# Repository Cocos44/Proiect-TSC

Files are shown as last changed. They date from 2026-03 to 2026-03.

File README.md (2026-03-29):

# Proiect InkTime - Smartwatch

Un smartwatch bazat pe microcontrollerul Nordic nRF52840 cu display e-Paper.

---

## Diagrama bloc

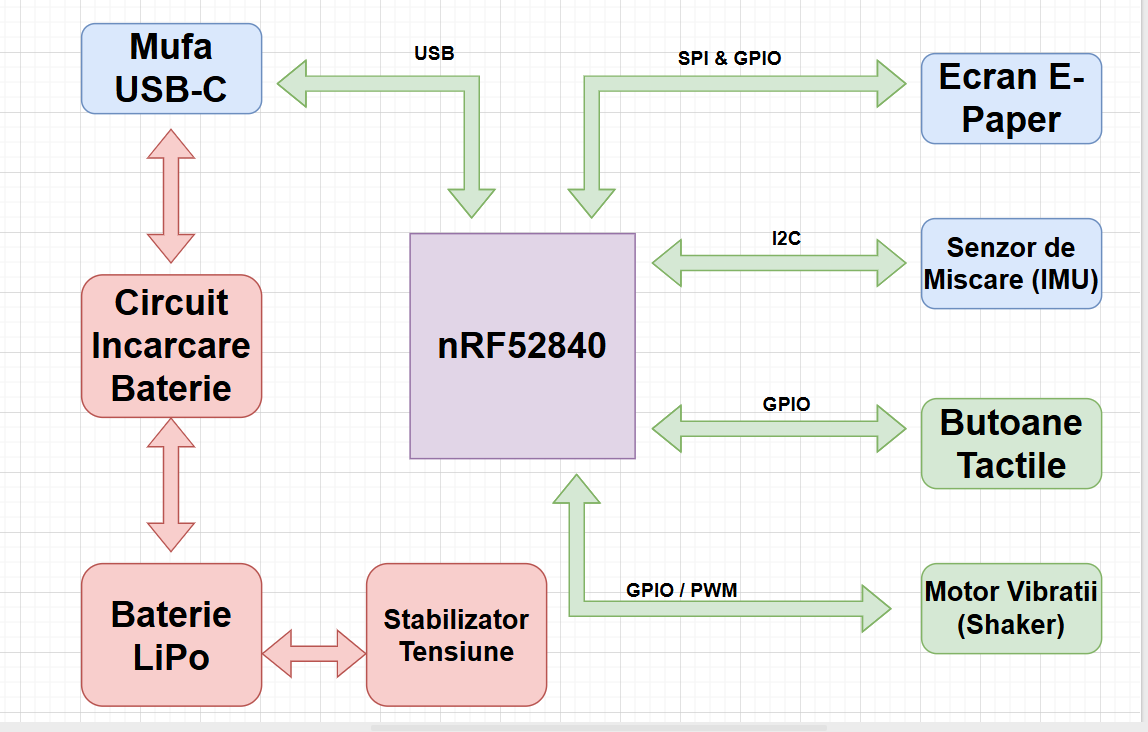
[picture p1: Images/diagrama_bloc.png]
Diagrama Bloc


---

## Bill of Materials

| Ref | Componenta | Valoare | JLC Parts | Datasheet |
|-----|---|---|---|---|
| U1 | nRF52840 | $5.14 | [JLC](https://jlcpcb.com/parts/componentSearch?searchTxt=nRF52840-QF) | [DS](https://jlcpcb.com/api/file/downloadByFileSystemAccessId/8589839228197629952) |
| SWD | TC2030-IDC | $100.26 | [JLC](https://jlcpcb.com/partdetail/MicrochipTech-TC2030_CLIP3PACK/C5444772) | [DS](https://www.lcsc.com/datasheet/lcsc_datasheet_2403201318_Microchip-Tech-TC2030-CLIP-3PACK_C5444772.pdf) |
| ANT1 | 2450AT18B100E | $1.03 | [JLC](https://jlcpcb.com/partdetail/JohansonDielectrics-2450AT18B100E/C2917717) | [DS](https://jlcpcb.com/api/file/downloadByFileSystemAccessId/8588940948130156544) |
| X1 | NX2016SA-32MHZ-EXS00A-CS11336 | $9.04 | [JLC](https://jlcpcb.com/partdetail/NDK-NX2016SA_32MHZ_EXS00ACS11336/C6134317) | [DS](https://jlcpcb.com/api/file/downloadByFileSystemAccessId/8603064888214908928) |
| L2 | RC0402JR-070RL | $0.01 | [JLC](https://jlcpcb.com/partdetail/YAGEO-RC0402JR070RL/C60485) | [DS](https://jlcpcb.com/api/file/downloadByFileSystemAccessId/8717146932348461056) |
| L3 | RC0402JR-070RL | $0.01 | [JLC](https://jlcpcb.com/partdetail/YAGEO-RC0402JR070RL/C60485) | [DS](https://jlcpcb.com/api/file/downloadByFileSystemAccessId/8717146932348461056) |
| X2 | FC-135_32.7680KA-A3 | $0.2677 | [JLC](https://jlcpcb.com/partdetail/SeikoEpson-FC_135_32_7680KAA3/C2650472) | [DS](https://jlcpcb.com/partdetail/SeikoEpson-FC_135_32_7680KAA3/C2650472) |
| IC3 | BMA423 | $11.30 | [JLC](https://jlcpcb.com/partdetail/BoschSensortec-BMA423/C189517) | [DS](https://jlcpcb.com/api/file/downloadByFileSystemAccessId/8588894317147017216) |
| IC9 | RT6160 | $0.56 | [JLC](https://jlcpcb.com/partdetail/RichtekTech-RT6160AWSC/C7065276) | [DS](https://jlcpcb.com/api/file/downloadByFileSystemAccessId/8600398231234883584) |
| L7 | MLP2016SR47MT0S1 | $0.10 | [JLC](https://jlcpcb.com/partdetail/TDK-MLP2016SR47MT0S1/C87545) | [DS](https://jlcpcb.com/api/file/downloadByFileSystemAccessId/8588933367512879104) |
| IC1 | BQ25180YBGR | $2.01 | [JLC](https://jlcpcb.com/partdetail/TexasInstruments-BQ25180YBGR/C3682423) | [DS](https://www.ti.com/cn/lit/gpn/bq25180) |
| L5 | 744043680 | $9.53 | [JLC](https://jlcpcb.com/partdetail/WurthElektronik-744043680/C2045671) | [DS](https://www.we-online.com/components/products/datasheet/744043680.pdf) |
| D2 | MBR0530 | $0.03 | [JLC](https://jlcpcb.com/partdetail/78464-MBR0530/C77336) | [DS](https://jlcpcb.com/api/file/downloadByFileSystemAccessId/8586175081181818880) |
| D4 | MBR0530 | $0.03 | [JLC](https://jlcpcb.com/partdetail/78464-MBR0530/C77336) | [DS](https://jlcpcb.com/api/file/downloadByFileSystemAccessId/8586175081181818880) |
| D5 | MBR0530 | $0.03 | [JLC](https://jlcpcb.com/partdetail/78464-MBR0530/C77336) | [DS](https://jlcpcb.com/api/file/downloadByFileSystemAccessId/8586175081181818880) |
| Q3 | SI1308EDL-T1-GE3 | $0.18 | [JLC](https://jlcpcb.com/partdetail/VishayIntertech-SI1308EDL_T1GE3/C469327) | [DS](https://jlcpcb.com/api/file/downloadByFileSystemAccessId/8588884784742846464) |
| Q1 | DMG2305UX-7 | $0.10 | [JLC](https://jlcpcb.com/partdetail/DiodesIncorporated-DMG2305UX7/C150470) | [DS](https://jlcpcb.com/api/file/downloadByFileSystemAccessId/8560079443617075200) |
| IC2 | DRV2605YZFR | $1.31 | [JLC](https://jlcpcb.com/partdetail/TexasInstruments-DRV2605YZFR/C81079) | [DS](https://www.ti.com/cn/lit/gpn/drv2605) |
| D3 | USBLC6-2SC6Y | $0.24 | [JLC](https://jlcpcb.com/partdetail/STMicroelectronics-USBLC62SC6Y/C2969755) | [DS](https://jlcpcb.com/api/file/downloadByFileSystemAccessId/8603165824304111616) |
| J4 | KH-TYPE-C-16P | $0.08 | [JLC](https://jlcpcb.com/partdetail/Shenzhen_KinghelmElec-KH_TYPE_C16P/C709357) | [DS](https://jlcpcb.com/api/file/downloadByFileSystemAccessId/8588905154556923904) |
| U3 | MAX17048G-T10 | $2.44 | [JLC](https://jlcpcb.com/partdetail/2777647-MAX17048GT10/C2682616) | [DS](https://jlcpcb.com/api/file/downloadByFileSystemAccessId/8588907428524003328) |
| J1 | 503480-2400 | $0.84 | [JLC](https://jlcpcb.com/partdetail/MOLEX-5034802400/C122434) | [DS](https://www.molex.com/content/dam/molex/molex-dot-com/products/automated/en-us/salesdrawingpdf/503/503480/5034802400_sd.pdf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) |

---

## Descriere Functionalitate Hardware

### Microcontroller - nRF52840
 Caracteristici principale:
- ARM Cortex-M4 la 64 MHz
- 1MB Flash, 256KB RAM
- Bluetooth 5.0 / BLE integrat
- Radio 2.4GHz cu suport pentru antena externa
- Interfete multiple: SPI, I2C, UART, GPIO
 
### Display E-Paper - Waveshare 1.54" V2
 
Display-ul comunica prin SPI pe 4 fire:
- Rezolutie: 200x200 pixeli
- Consum ultra-redus - retine imaginea fara alimentare
- Conectat la nRF52840 prin conectorul FPC 24 pini (503480-2400)
 
### IMU - BMA423
 
Accelerometrul BMA423 comunica prin I2C:
- Accelerometru pe 3 axe
- Numarare pasi, recunoastere activitate
 
### Incarcator Baterie - BQ25180
 
BQ25180 gestioneaza incarcarea bateriei prin I2C:
- Intrare: USB-C 5V
- Iesire: 3.7V LiPo
- Curent maxim de incarcare: 250mA
 
### Baterie - AKYGA LP502030
 
- Dimensiuni: 32.5mm x 21mm x 5.5mm
- Conectata direct la doua test pad-uri de pe placa
 
### Motor Vibratii - FIT0774
 
- Controlat prin GPIO via driver haptic DRV2605
- Diametru: 10mm, Inaltime: 2.7mm
- Tensiune de operare: 1.5-4.2V
 
### Conector Debug - TC2030-IDC
 
- Conector Tag-Connect 10 pini
- Folosit pentru programare si debugging SWD
- Semnale: SWDIO, SWDCLK, GND, VCC, RESET
 
---
 
## Pinii nRF52840
 
| Pin nRF52840 | Semnal | Componenta | Interfata |
|---|---|---|---|
| P0.00/XL1 | XL1 | Crystal X2 (32.768kHz) | XTAL |
| P0.01/XL2 | XL2 | Crystal X2 (32.768kHz) | XTAL |
| P0.05/AIN3 | EPD_CS | E-Paper (J1 FPC) | SPI CS |
| P0.06 | SDA | BMA423, BQ25180, MAX17048, DRV2605 | I2C SDA |
| P0.07 | SCL | BMA423, BQ25180, MAX17048, DRV2605 | I2C SCL |
| P0.08 | IMU_INT1 | BMA423 | GPIO Input |
| P1.08 | IMU_INT2 | BMA423 | GPIO Input |
| P0.11 | PMIC_INT | BQ25180 | GPIO Input |
| P0.12 | HAPTIC_EN | DRV2605 | GPIO |
| VBUS | VBUS | USB-C (J4) | Power |
| D- | D- | USB-C (J4) / USBLC6 | USB |
| D+ | D+ | USB-C (J4) / USBLC6 | USB |
| P0.13 | SW_UP | Buton Up | GPIO Input |
| P0.14 | SW_ENT | Buton Enter | GPIO Input |
| P0.15 | EPD_DC | E-Paper (J1 FPC) | SPI DC |
| P0.16 | EPD_RST | E-Paper (J1 FPC) | GPIO |
| P0.17 | EPD_BUSY | E-Paper (J1 FPC) | GPIO Input |
| P0.18/RESET | RESET | TC2030-IDC | SWD/GPIO |
| SWDCLK | SWDCLK | TC2030-IDC | SWD |
| SWDIO | SWDIO | TC2030-IDC | SWD |
| P1.02 | SW_DN | Buton Down | GPIO Input |
| P0.10/NFC2 | ALERT | MAX17048 | GPIO Input |
| ANT | RF | Antena 2450AT18B100E | RF |
| P0.02/AIN0 | SCK | E-Paper (J1 FPC) | SPI SCK |
| P0.03/AIN1 | MOSI | E-Paper (J1 FPC) | SPI MOSI |
 
---

## Jurnal de Design si Pasi de Implementare (Design Log)

### Pasi realizare PCB
* Plasarea componentelor majore: Am inceput prin a pozitiona componentele mari si cele cu constrangeri mecanice stricte (mufa USB, butoanele laterale, conectorul de display si microcontrollerul). Imediat dupa plasarea componentelor principale, am legat componentele mici (condensatoare, rezistente, etc.). In final, am pus Polygon Pour pe toate planurile infara de cel de POWER.

* Dupa plasarea componentelor in PCB, am inceput rutarea mai intai cu traseele de putere, urmand dupa cu restul.

* Rutarea (Top/Bottom): Traseele au fost rutate evitand unghiurile drepte. Liniile de alimentare au fost dimensionate cu latimea de 0.3mm (variind sub zonele dense BGA/QFN), iar cele de date la 0.15mm. Zona de sub antena radio a fost curatata complet de cupru si semnale.

### Erori DRC acceptate
* Copper Clearance: In zona pad-urilor BGA ale nRF52840, distanta minima dintre pad-uri este impusa de producator si nu poate fi modificata. Erorile sunt inevitabile si acceptate de JLCPCB.

* Overlap: Aceste erori apar din cauza tehnicii Via-in-Pad. Via-urile plasate direct in pad-urile componentei se suprapun geometric cu traseele adiacente.

* Drill Size: Via-urile folosite pentru Via-in-Pad au diametrul mai mic decat minimul din regulile DRC standard, ales intentionat pentru a incapea in pad-urile mici ale nRF52840.

* Board Outline Clearance. Erori de la mufa USB-C.
---

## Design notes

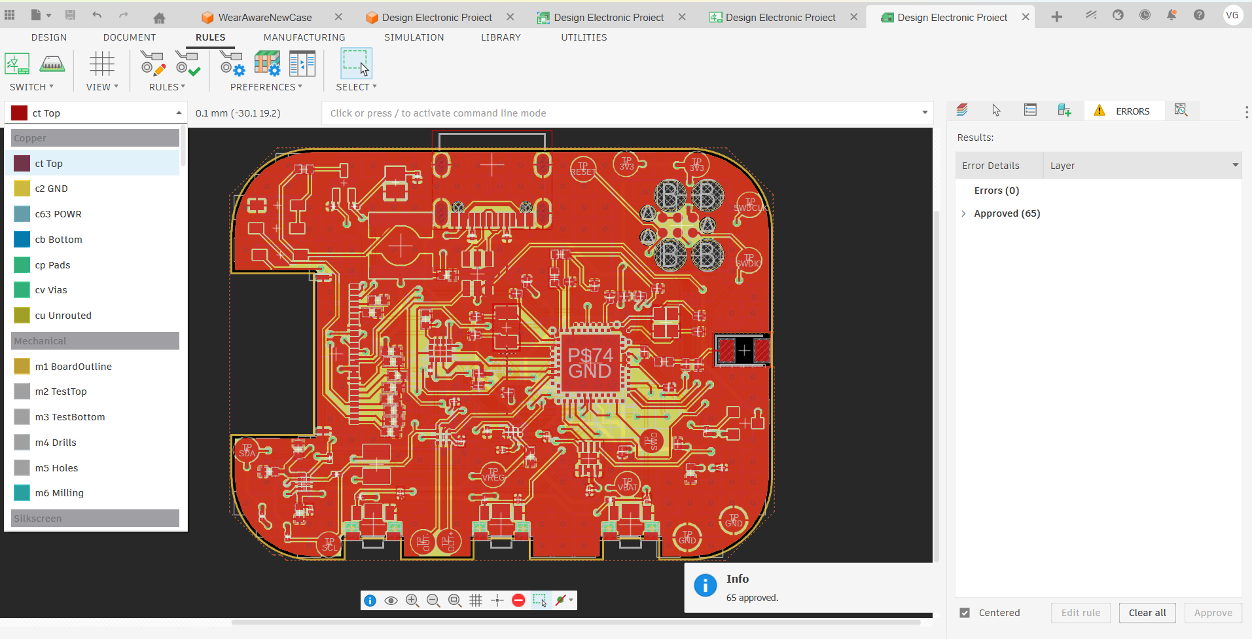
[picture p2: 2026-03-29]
Images/pcb_plus_rulare_drc.png

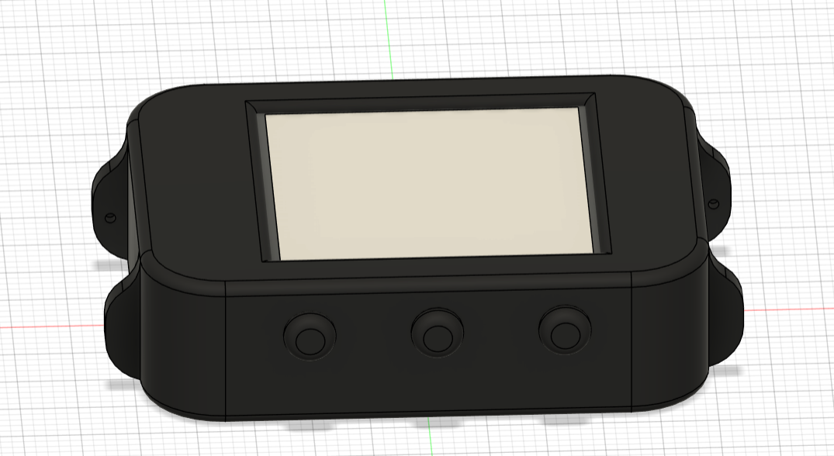
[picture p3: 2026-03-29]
Images/ceas_forma_finala.png

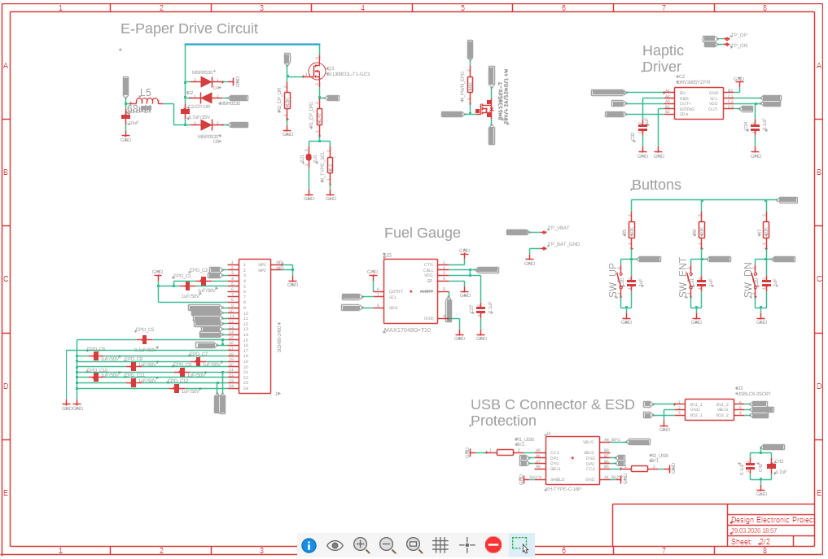
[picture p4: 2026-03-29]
Images/schema_electrica_fisa_2.png

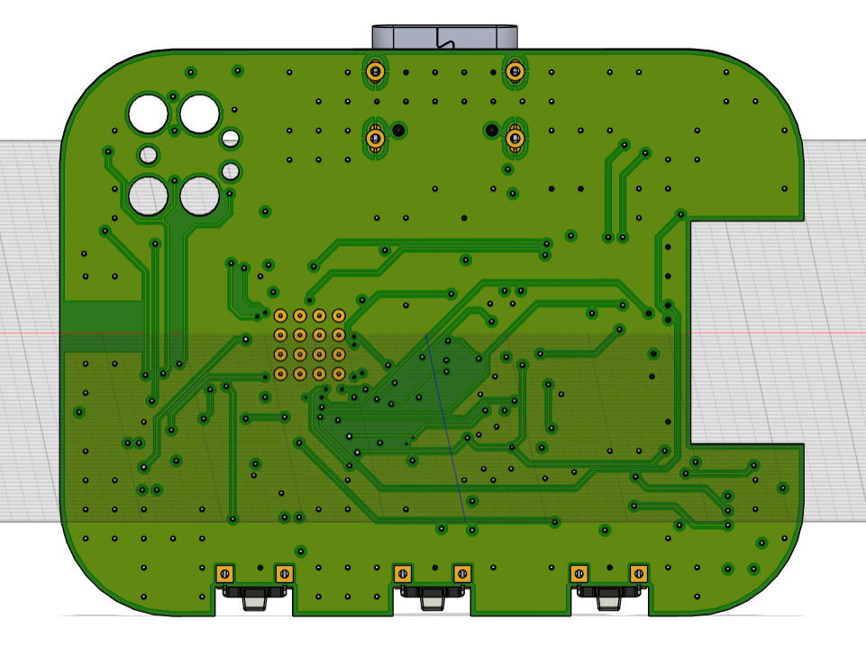
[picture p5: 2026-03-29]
Images/pcb-3D_spate.png

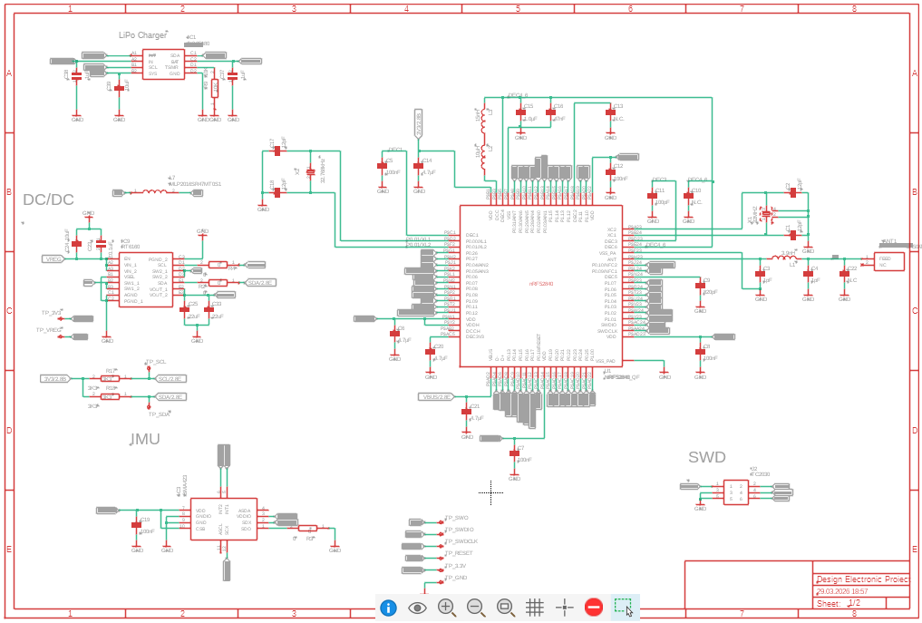
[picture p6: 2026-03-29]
Images/schema_electrica_fisa_1.png

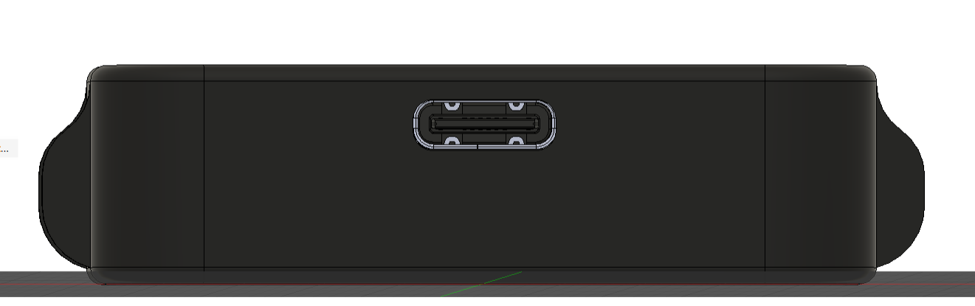
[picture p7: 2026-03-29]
Images/ceas_mufa_usb_plasare_corecta.png

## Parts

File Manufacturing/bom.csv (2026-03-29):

Qty | Value | Device | Package | Parts | Description | 2450AT18B100E | ARROW_PART_NUMBER | ARROW_PRICE-STOCK | AVAILABILITY | BQ25180 | BQ25180YBGR | CHECK_PRICES | COPYRIGHT | DESCRIPTION | DIGI-KEY_PART_NUMBER_1 | DIGI-KEY_PART_NUMBER_2 | DIGI-KEY_PART_NUMBER_3 | HEIGHT | JLCPCB | MANUFACTURER_NAME | MANUFACTURER_PART_NUMBER | MF | MFR_NAME | MOUSER_PART_NUMBER | MOUSER_PRICE-STOCK | MP | NRF52840_QF | PACKAGE | POPULARITY | PRICE | PROD_ID | PURCHASE-URL | R1 | SHOW_VALUE | SNAPEDA_LINK | TP_SIGNAL_NAME | VALUE
1 | nRF52840 | NORDIC_NRF_4_NRF52840_QF | NORDIC_NRF_4_AQFN50P700X700X85_HS-74N | U1 | nRF52840
3 | 0 | CPF0201D7K68C1_CPF0201D7K68C1 | CPF0201D7K68C1_0201 | R2, R3, R4 | 7.68k 0201 Thin Film Surface Mount Fixed Resistor +/-0.5% 0.031W CPF0201D7K68C1 |  |  |  |  |  |  |  |  |  |  |  |  |  |  |  |  |  |  |  |  |  |  |  |  |  |  |  | 0
4 | 0.1uF | GRM011R60J152KE01L_2_GRM011R60J152KE01L | GRM011R60J152KE01L_2_CAPC0201X13N | C23, C27, C34, C42 | Check availability |  |  |  | In Stock |  |  | https://www.snapeda.com/parts/GRM011R60J152KE01L/Murata/view-part/?ref=eda |  | SMD Capacitor X5R(EIA) with Capacitance: 1500pF Tol. 10%. Rated Voltage: 6.3Vdc |  |  |  |  |  |  |  | Murata |  |  |  | GRM011R60J152KE01L |  | 0201 Murata |  | None |  |  |  |  | https://www.snapeda.com/parts/GRM011R60J152KE01L/Murata/view-part/?ref=snap
1 | 0.1uF/50V | NORDIC_NRF_3_CAPACITOR_0402_L | NORDIC_NRF_3_RESC0402_L | EPD_C5 | Generic chip capacitor
1 | 0.47 | CPF0201D7K68C1_CPF0201D7K68C1 | CPF0201D7K68C1_0201 | R1_EP_DR1 | 7.68k 0201 Thin Film Surface Mount Fixed Resistor +/-0.5% 0.031W CPF0201D7K68C1
1 | 1.0µF | NORDIC_NRF_3_CAPACITOR_0201_L | NORDIC_NRF_3_RESC0201_L | C15 | Generic chip capacitor
4 | 100nF | NORDIC_NRF_3_CAPACITOR_0201_L | NORDIC_NRF_3_RESC0201_L | C5, C7, C8, C12 | Generic chip capacitor
1 | 100nF | NORDIC_NRF_3_CAPACITOR_0402_L | NORDIC_NRF_3_RESC0402_L | C19 | Generic chip capacitor
1 | 100pF | NORDIC_NRF_3_CAPACITOR_0201_L | NORDIC_NRF_3_RESC0201_L | C11 | Generic chip capacitor
5 | 10K | CPF0201D7K68C1_CPF0201D7K68C1 | CPF0201D7K68C1_0201 | R2_EP_DR, R5, R7, R8, R_PWR_EPD | 7.68k 0201 Thin Film Surface Mount Fixed Resistor +/-0.5% 0.031W CPF0201D7K68C1
1 | 10K | CPF0201D7K68C1_CPF0201D7K68C1 | CPF0201D7K68C1_0201 | R9 | 7.68k 0201 Thin Film Surface Mount Fixed Resistor +/-0.5% 0.031W CPF0201D7K68C1 |  |  |  |  |  |  |  |  |  |  |  |  |  |  |  |  |  |  |  |  |  |  |  |  |  |  |  | 10K
3 | 10uF | NORDIC_NRF_3_CAPACITOR_0402_L | NORDIC_NRF_3_RESC0402_L | C1-EP-DR, C24, C39 | Generic chip capacitor
1 | 10µH | NORDIC_NRF_2_INDUCTOR_0402_L | NORDIC_NRF_2_RESC0402_L | L2 | Generic chip inductor
4 | 12pF | NORDIC_NRF_3_CAPACITOR_0201_L | NORDIC_NRF_3_RESC0201_L | C1, C2, C17, C18 | Generic chip capacitor
1 | 15nH | NORDIC_NRF_2_INDUCTOR_0402_L | NORDIC_NRF_2_RESC0402_L | L3 | Generic chip inductor
2 | 1pF | NORDIC_NRF_3_CAPACITOR_0201_L | NORDIC_NRF_3_RESC0201_L | C3, C4 | Generic chip capacitor
6 | 1uF | GRM011R60J152KE01L_2_GRM011R60J152KE01L | GRM011R60J152KE01L_2_CAPC0201X13N | C29, C30, C31, C32, C37, C38 | Check availability |  |  |  | In Stock |  |  | https://www.snapeda.com/parts/GRM011R60J152KE01L/Murata/view-part/?ref=eda |  | SMD Capacitor X5R(EIA) with Capacitance: 1500pF Tol. 10%. Rated Voltage: 6.3Vdc |  |  |  |  |  |  |  | Murata |  |  |  | GRM011R60J152KE01L |  | 0201 Murata |  | None |  |  |  |  | https://www.snapeda.com/parts/GRM011R60J152KE01L/Murata/view-part/?ref=snap
9 | 1uF/50V | NORDIC_NRF_3_CAPACITOR_0402_L | NORDIC_NRF_3_RESC0402_L | EPD_C1, EPD_C2, EPD_C6, EPD_C7, EPD_C8, EPD_C9, EPD_C10, EPD_C11, EPD_C12 | Generic chip capacitor
1 | 2.2 | CPF0201D7K68C1_CPF0201D7K68C1 | CPF0201D7K68C1_0201 | R_TYPE_SEL | 7.68k 0201 Thin Film Surface Mount Fixed Resistor +/-0.5% 0.031W CPF0201D7K68C1
3 | 2025-10-22_07-23-44_LIBRARY_EVP-AKE31ASW_EVP-AKE31A_PAN | 2025-10-22_07-23-44_LIBRARY_EVP-AKE31ASW_EVP-AKE31A_PAN | 2025-10-22_07-23-44_LIBRARY_SW_EVP-AKE31A_PAN | SW_DN, SW_ENT, SW_UP |  |  |  |  |  |  |  |  | Copyright (C) 2025 Ultra Librarian. All rights reserved. |  | P123437TR-ND | P123437CT-ND | P123437DKR-ND |  |  | Panasonic | EVP-AKE31A
1 | 20V/4.2A/52m?/1.4W | ESP32_C6_LIBRARY_4_ESP32_WROVER_SPARKFUN-DISCRETESEMI_MOSFET_PCH-DMG2305UX-7 | ESP32_C6_LIBRARY_4_ESP32_C6_LIBRARY_4_ESP32_C6_LIBRARY_4_ESP32_C6_LIBRARY_4_ESP32_WROVER_SPARKFUN-DISCRETESEMI_SOT23-3 | DMG2305UX-7 | P-channel MOSFETs |  |  |  |  |  |  |  |  |  |  |  |  |  |  |  |  |  |  |  |  |  |  |  |  |  | TRAN-14388 |  |  |  |  |  | 20V/4.2A/52m?/1.4W
2 | 22uF | NORDIC_NRF_3_CAPACITOR_0402_L | NORDIC_NRF_3_RESC0402_L | C25, C33 | Generic chip capacitor
1 | 2450AT18B100E_2450AT18B100E | 2450AT18B100E_2450AT18B100E | 2450AT18B100E_ANTC3216X140N | ANT1 | Antennas 2.45GHz ANTENNA |  | 2450AT18B100E | https://www.arrow.com/en/products/2450at18b100e/johanson-dielectrics?utm_currency=USD&region=nac |  |  |  |  |  | Antennas 2.45GHz ANTENNA |  |  |  | 1.4mm |  | JOHANSON TECHNOLOGY | 2450AT18B100E |  |  | 609-2450AT18B100E | https://www.mouser.co.uk/ProductDetail/Johanson-Technology/2450AT18B100E?qs=yCnrNFeXz%252Bh5MFsFIXGZGA%3D%3D
1 | 3.9nH | NORDIC_NRF_2_INDUCTOR_0402_L | NORDIC_NRF_2_RESC0402_L | L1 | Generic chip inductor
1 | 32.768kHz | NORDIC_NRF_1_XTAL_32KHZ | NORDIC_NRF_1_XTAL_3215_N | X2
1 | 32MHZ | NORDIC_NRF_XTAL_32MHZ | NORDIC_NRF_BT-XTAL_2016_N | X1
2 | 3K3 | CPF0201D7K68C1_CPF0201D7K68C1 | CPF0201D7K68C1_0201 | R17, R18 | 7.68k 0201 Thin Film Surface Mount Fixed Resistor +/-0.5% 0.031W CPF0201D7K68C1 |  |  |  |  |  |  |  |  |  |  |  |  |  |  |  |  |  |  |  |  |  |  |  |  |  |  |  | 3K3
1 | 4.7uF | NORDIC_NRF_3_CAPACITOR_0402_L | NORDIC_NRF_3_RESC0402_L | C43 | Generic chip capacitor
1 | 4.7uF/25V | NORDIC_NRF_3_CAPACITOR_0402_L | NORDIC_NRF_3_RESC0402_L | C2-EP-DR | Generic chip capacitor
4 | 4.7µF | NORDIC_NRF_3_CAPACITOR_0201_L | NORDIC_NRF_3_RESC0201_L | C6, C14, C20, C21 | Generic chip capacitor
1 | 47nF | NORDIC_NRF_3_CAPACITOR_0201_L | NORDIC_NRF_3_RESC0201_L | C16 | Generic chip capacitor
1 | 503480-2400 | 503480-2400_503480-2400 | 503480-2400_5034802400 | J1 | FFC & FPC Connectors 0.5mm FPC RA SMT Dual Contact 24Ckt |  |  |  |  |  |  |  |  | FFC & FPC Connectors 0.5mm FPC RA SMT Dual Contact 24Ckt |  |  |  | 1.87mm |  | Molex | 503480-2400 |  |  | 538-503480-2400 | https://www.mouser.co.uk/ProductDetail/Molex/503480-2400?qs=OAhjpuo3Vu7efIoxFh9AOw%3D%3D
2 | 5K1 | CPF0201D7K68C1_CPF0201D7K68C1 | CPF0201D7K68C1_0201 | R1_USB, R2_USB | 7.68k 0201 Thin Film Surface Mount Fixed Resistor +/-0.5% 0.031W CPF0201D7K68C1
1 | 68uH | ESP32_C6_LIBRARY_2_744043680IND_4828-WE-TPC_WRE | ESP32_C6_LIBRARY_2_IND_4828-WE-TPC_WRE | L5 |  |  |  |  |  |  |  |  | Copyright (C) 2024 Ultra Librarian. All rights reserved. |  |  |  |  |  |  |  | 744043680 |  | Wurth Electronics |  |  |  |  |  |  |  |  |  |  | 68uH
1 | 820pF | NORDIC_NRF_3_CAPACITOR_0201_L | NORDIC_NRF_3_RESC0201_L | C9 | Generic chip capacitor
1 | BMA423 | BMA423_BMA423 | BMA423_BMA423 | IC3 | Accelerometers Triaxial low-g 12bit Acceleration Sensor |  | BMA423 | https://www.arrow.com/en/products/bma423/bosch |  |  |  |  |  | Accelerometers Triaxial low-g 12bit Acceleration Sensor |  |  |  | 1mm |  | BOSCH | BMA423 |  |  | 262-BMA423 | https://www.mouser.co.uk/ProductDetail/Bosch-Sensortec/BMA423?qs=HXFqYaX1Q2xC%252BSgeGoX3mg%3D%3D
1 | BQ25180 | BQ25180YBGR_BQ25180YBGR | BQ25180YBGR_BGA8C40P2X4_100X155X50 | IC1 | Charger IC Lithium Ion/Polymer, Lithium Iron Phosphate 8-DSBGA (1.6x1.1) |  | BQ25180YBGR | https://www.arrow.com/en/products/bq25180ybgr/texas-instruments?utm_currency=USD&region=nac |  |  |  |  |  | Charger IC Lithium Ion/Polymer | Lithium Iron Phosphate 8-DSBGA (1.6x1.1) |  |  |  | 0.5mm |  | Texas Instruments | BQ25180YBGR |  |  | 595-BQ25180YBGR | https://www.mouser.co.uk/ProductDetail/Texas-Instruments/BQ25180YBGR?qs=doiCPypUmgEWjAK%252BJAX6Tw%3D%3D
1 | DRV2605YZFR | DRV2605YZFR_DRV2605YZFR | DRV2605YZFR_BGA9C50P3X3_144X144X62 | IC2 | Haptic Driver for ERM/LRA with Built-In Library and Smart Loop Architecture |  | DRV2605YZFR | https://www.arrow.com/en/products/drv2605yzfr/texas-instruments?region=nac |  |  |  |  |  | Haptic Driver for ERM/LRA with Built-In Library and Smart Loop Architecture |  |  |  | 0.625mm |  | Texas Instruments | DRV2605YZFR
14 | HECTOR_WATCH_1_TPTP20R | HECTOR_WATCH_1_TPTP20R | HECTOR_WATCH_1_TP20R | TP_3.3V, TP_3V3, TP_BAT_GND, TP_GND, TP_ON, TP_OP, TP_RESET, TP_SCL, TP_SDA, TP_SWDCLK, TP_SWDIO, TP_SWO, TP_VBAT, TP_VREG | Test pad |  |  |  |  |  |  |  |  |  |  |  |  |  |  |  |  |  |  |  |  |  |  |  | 2
1 | KH-TYPE-C-16P | KH-TYPE-C-16P_KH-TYPE-C-16P | KH-TYPE-C-16P_KINGHELM_KH-TYPE-C-16P | J4 | Check availability |  |  |  | Not in stock |  |  | https://www.snapeda.com/parts/KH-TYPE-C-16P/Kinghelm/view-part/?ref=eda |  |  |  |  |  |  |  |  |  | kinghelm |  |  |  | KH-TYPE-C-16P |  | None |  | None |  |  |  |  | https://www.snapeda.com/parts/KH-TYPE-C-16P/Kinghelm/view-part/?ref=snap
1 | MAX17048G+T10 | ESP32_C6_LIBRARY_MAX17048G+T10 | ESP32_C6_LIBRARY_SON50P200X200X80-9N | U3 | Check availability |  |  |  | In Stock |  |  | https://www.snapeda.com/parts/MAX17048G+T10/Analog+Devices/view-part/?ref=eda |  | 3µA 1-Cell/2-Cell Fuel Gauge with ModelGauge |  |  |  |  |  |  |  | Analog Devices |  |  |  | MAX17048G+T10 |  | TDFN-8 Maxim |  | None |  | https://www.snapeda.com/api/url_track_click_mouser/?unipart_id=329239&manufacturer=Analog Devices&part_name=MAX17048G+T10&search_term=None |  |  | https://www.snapeda.com/parts/MAX17048G+T10/Analog+Devices/view-part/?ref=snap
3 | MBR0530 | ESP32_C6_LIBRARY_5_MBR0530 | ESP32_C6_LIBRARY_5_SOD3716X135N | D2, D4, D5 | ON SEMICONDUCTOR - MBR0530 - DIODE, SCHOTTKY, 0.5A, 30V, SOD-123 |  |  |  | In Stock |  |  | https://www.snapeda.com/parts/MBR0530/Onsemi/view-part/?ref=eda |  | Diode Schottky 30 V 500mA Surface Mount SOD-123 |  |  |  |  |  |  |  | ON Semiconductor |  |  |  | MBR0530 |  | SOD-123-2 ON Semiconductor |  | None |  | https://www.snapeda.com/api/url_track_click_mouser/?unipart_id=179458&manufacturer=ON Semiconductor&part_name=MBR0530&search_term=None |  |  | https://www.snapeda.com/parts/MBR0530/Onsemi/view-part/?ref=snap
1 | MLP2016SR47MT0S1 | MLP2016SR47MT0S1_FTC252012SR47MBCA | MLP2016SR47MT0S1_INDC2016X100N | L7 | SMD / SMT Inductors (Coils), L=0.47?H, L x W x T : |  |  |  |  |  |  |  |  | SMD / SMT Inductors (Coils) | L=0.47?H | L x W x T : |  |  |  | 1mm | https://jlcpcb.com/partdetail/6763488-FTC252012SR47MBCA/C5832368 | TDK | FTC252012SR47MBCA
1 | N.C | NORDIC_NRF_3_CAPACITOR_0201_L | NORDIC_NRF_3_RESC0201_L | C22 | Generic chip capacitor
2 | N.C. | NORDIC_NRF_3_CAPACITOR_0201_L | NORDIC_NRF_3_RESC0201_L | C10, C13 | Generic chip capacitor
1 | RT6160 | RT6160AWSC_RT6160AWSC | RT6160AWSC_BGA15C40P3X5_140X230X60 | IC9 | Buck-Boost Regulator Positive Output Step-Up/Step-Down I2C DC-DC Controller IC 15-WL-CSP (BSC) (1.4x2.3) |  |  |  |  |  |  |  |  | Buck-Boost Regulator Positive Output Step-Up/Step-Down I2C DC-DC Controller IC 15-WL-CSP (BSC) (1.4x2.3) |  |  |  | 0.6mm |  | RICHTEK | RT6160AWSC |  |  | 835-RT6160AWSC | https://www.mouser.co.uk/ProductDetail/Richtek/RT6160AWSC?qs=amGC7iS6iy%2FLd9PSoixZXQ%3D%3D
1 | SI1308EDL-T1-GE3 | ESP32_C6_LIBRARY_6_SI1308EDL-T1-GE3 | ESP32_C6_LIBRARY_6_SOT65P210X110-3N | Q3 | MOSFET N-Ch 30V 1.5A TrenchFET SC70 Vishay Si1308EDL-T1-GE3 N-channel MOSFET Transistor, 1.5 A, 30 V, 3-Pin SC-70 |  |  |  | In Stock |  |  | https://www.snapeda.com/parts/SI1308EDL-T1-GE3/Vishay+Siliconix/view-part/?ref=eda |  | Si1308EDL-T1-GE3 N-channel MOSFET Transistor | 1.5 A | 30 V | 3-Pin SC-70 | Siliconix / Vishay SI1308EDL-T1-GE3 |  |  |  |  |  |  |  | Vishay Siliconix |  |  |  | SI1308EDL-T1-GE3 |  | SOT-323 Vishay Semiconductor |  | None |  | https://www.snapeda.com/api/url_track_click_mouser/?unipart_id=274603&manufacturer=Vishay Siliconix&part_name=SI1308EDL-T1-GE3&search_term=None
1 | SJ1 | ESP32_C6_LIBRARY_7_JUMPER_SJ | ESP32_C6_LIBRARY_7_JUMPER_SJ | SJ1 | SMD solder JUMPER |  |  |  |  |  |  |  |  |  |  |  |  |  |  |  |  |  |  |  |  |  |  |  | 3
1 | TC2030 | TC2030-IDC_TC2030-IDC | TC2030-IDC_TC2030IDC | J2 | CABLE ADAPTER 6 POS |  |  |  |  |  |  |  |  | CABLE ADAPTER 6 POS |  |  |  | 19mm |  | Tag Connect | TC2030-IDC
1 | USBLC6-2SC6Y | ESP32_C6_LIBRARY_3_USBLC6-2SC6Y | ESP32_C6_LIBRARY_3_SOT95P280X145-6N | D3 | Low Cap. ESD Protection Auto SOT-23-6 STMicroelectronics USBLC6-2SC6Y, Dual Uni-Directional TVS Diode Array, 6-Pin SOT-23 |  |  |  | In Stock |  |  | https://www.snapeda.com/parts/USBLC6-2SC6Y/STMicroelectronics/view-part/?ref=eda |  | 17V Clamp 5A (8/20µs) Ipp Tvs Diode Surface Mount SOT-23-6 |  |  |  |  |  |  |  | STMicroelectronics |  |  |  | USBLC6-2SC6Y |  | SOT-23-6 STMicroelectronics |  | None |  |  |  |  | https://www.snapeda.com/parts/USBLC6-2SC6Y/STMicroelectronics/view-part/?ref=snap

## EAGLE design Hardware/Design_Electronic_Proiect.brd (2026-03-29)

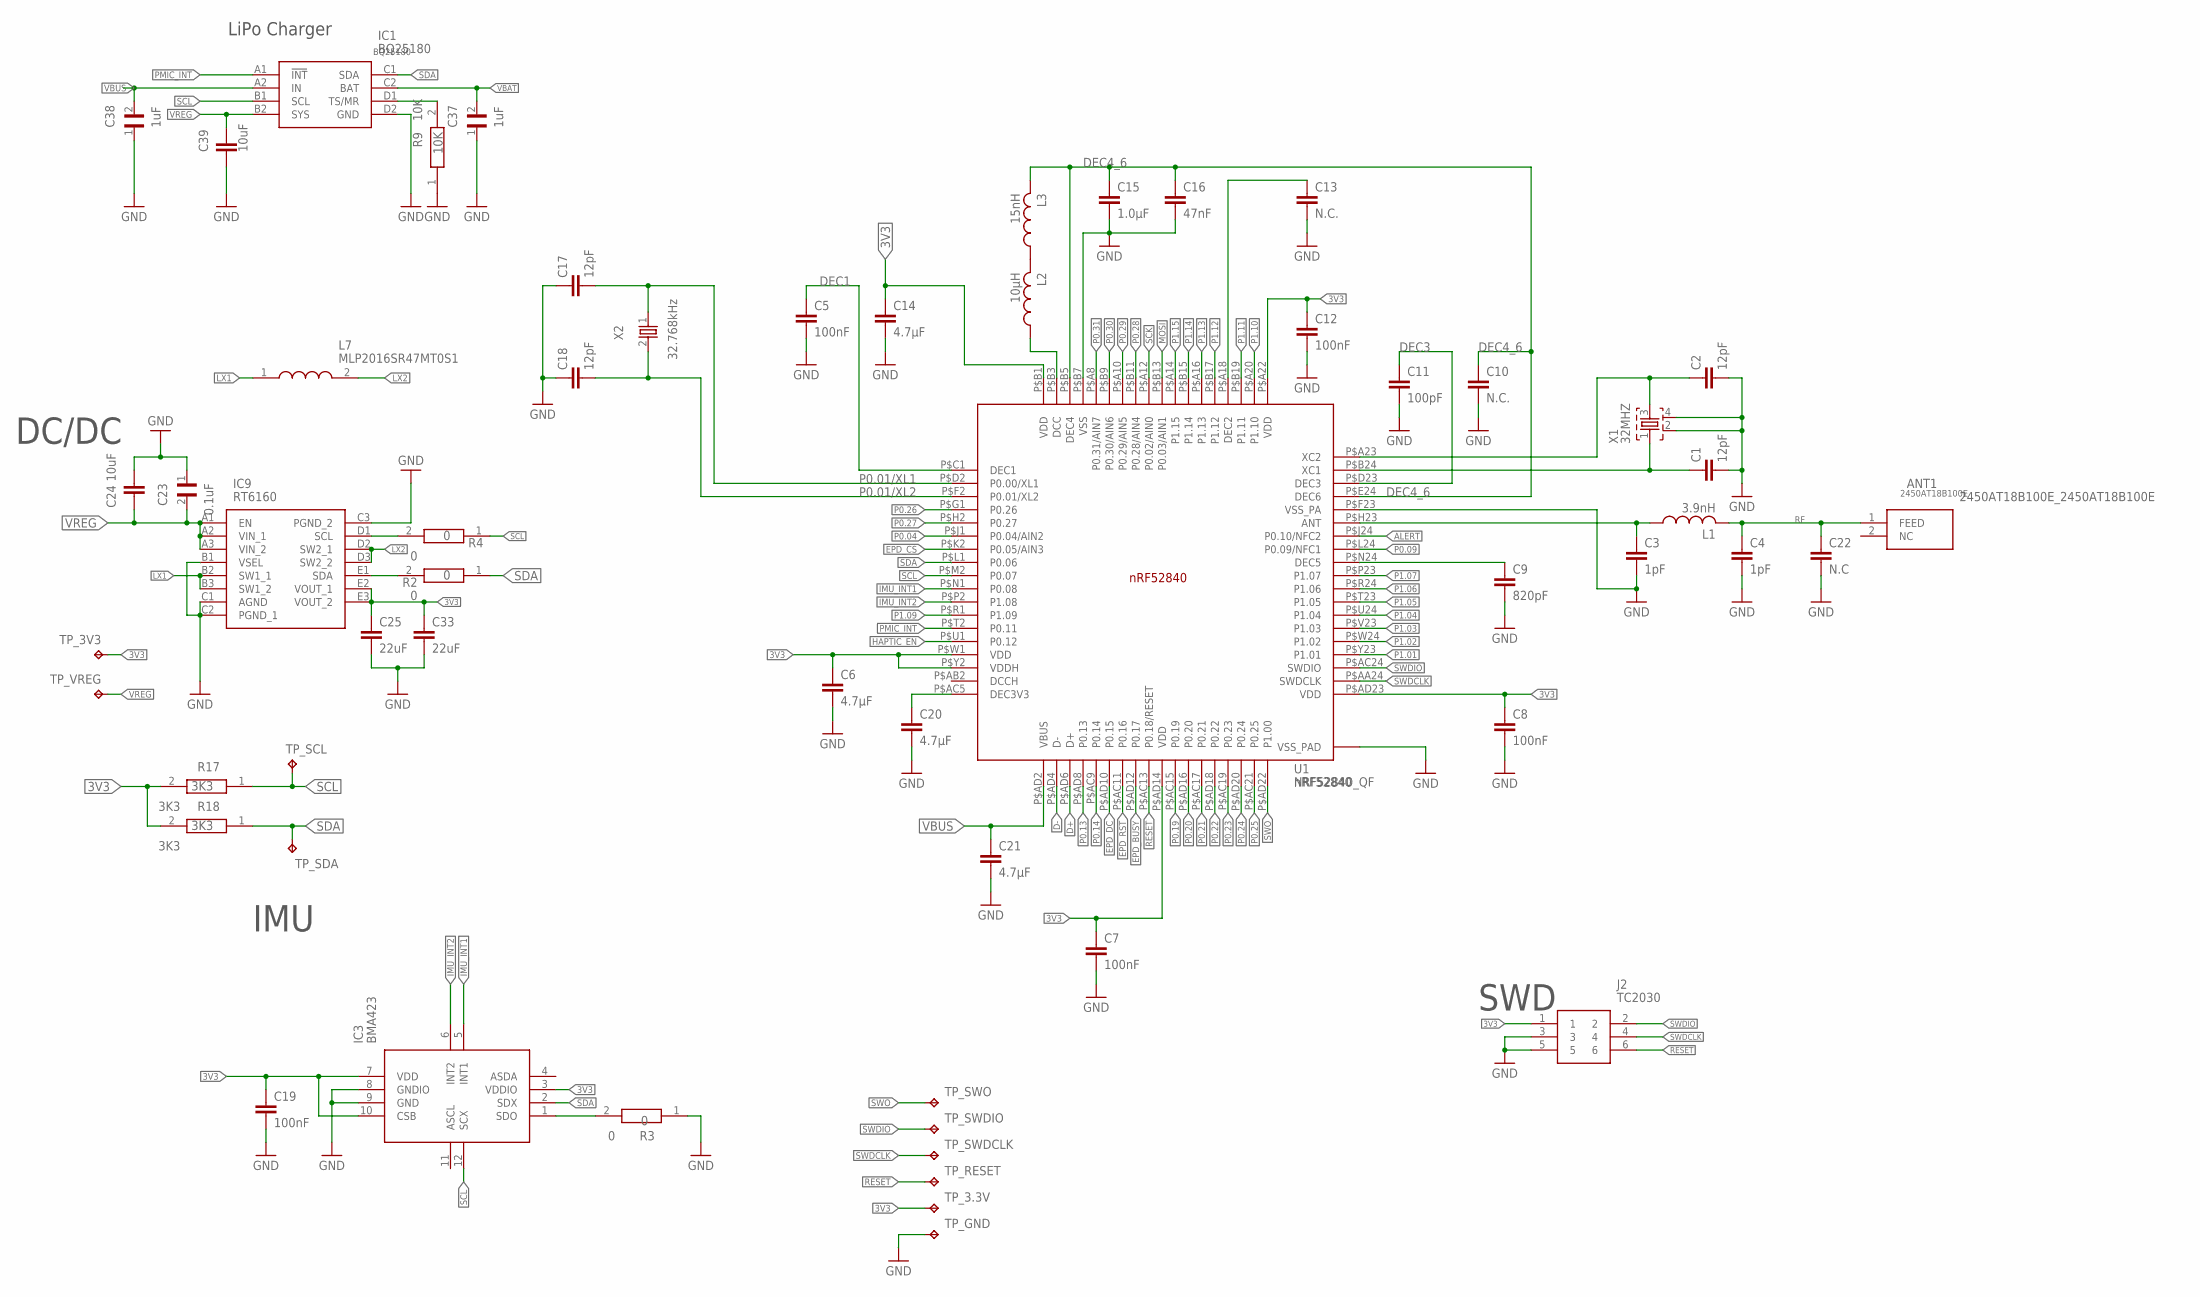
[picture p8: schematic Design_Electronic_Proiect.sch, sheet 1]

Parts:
ANT1: 2450AT18B100E_2450AT18B100E; 2450AT18B100E_ANTC3216X140N
C1, C2, C17, C18: 12pF; NORDIC_NRF_3_RESC0201_L
C3, C4: 1pF; NORDIC_NRF_3_RESC0201_L
C5, C7, C8, C12: 100nF; NORDIC_NRF_3_RESC0201_L
C6, C14, C20, C21: 4.7µF; NORDIC_NRF_3_RESC0201_L
C9: 820pF; NORDIC_NRF_3_RESC0201_L
C10, C13: N.C.; NORDIC_NRF_3_RESC0201_L
C11: 100pF; NORDIC_NRF_3_RESC0201_L
C15: 1.0µF; NORDIC_NRF_3_RESC0201_L
C16: 47nF; NORDIC_NRF_3_RESC0201_L
C19: 100nF; NORDIC_NRF_3_RESC0402_L
C22: N.C; NORDIC_NRF_3_RESC0201_L
C23: 0.1uF; GRM011R60J152KE01L_2_CAPC0201X13N
C24, C39: 10uF; NORDIC_NRF_3_RESC0402_L
C25, C33: 22uF; NORDIC_NRF_3_RESC0402_L
C37, C38: 1uF; GRM011R60J152KE01L_2_CAPC0201X13N
IC1: BQ25180; BQ25180YBGR_BGA8C40P2X4_100X155X50
IC3: BMA423; BMA423_BMA423
IC9: RT6160; RT6160AWSC_BGA15C40P3X5_140X230X60
J2: TC2030; TC2030-IDC_TC2030IDC
L1: 3.9nH; NORDIC_NRF_2_RESC0402_L
L2: 10µH; NORDIC_NRF_2_RESC0402_L
L3: 15nH; NORDIC_NRF_2_RESC0402_L
L7: MLP2016SR47MT0S1; MLP2016SR47MT0S1_INDC2016X100N
R2, R3, R4: 0; CPF0201D7K68C1_0201
R9: 10K; CPF0201D7K68C1_0201
R17, R18: 3K3; CPF0201D7K68C1_0201
TP_3.3V, TP_3V3: HECTOR_WATCH_1_TPTP20R; HECTOR_WATCH_1_TP20R
TP_GND: HECTOR_WATCH_1_TPTP20R; HECTOR_WATCH_1_TP20R
TP_RESET: HECTOR_WATCH_1_TPTP20R; HECTOR_WATCH_1_TP20R
TP_SCL: HECTOR_WATCH_1_TPTP20R; HECTOR_WATCH_1_TP20R
TP_SDA: HECTOR_WATCH_1_TPTP20R; HECTOR_WATCH_1_TP20R
TP_SWDCLK: HECTOR_WATCH_1_TPTP20R; HECTOR_WATCH_1_TP20R
TP_SWDIO: HECTOR_WATCH_1_TPTP20R; HECTOR_WATCH_1_TP20R
TP_SWO: HECTOR_WATCH_1_TPTP20R; HECTOR_WATCH_1_TP20R
TP_VREG: HECTOR_WATCH_1_TPTP20R; HECTOR_WATCH_1_TP20R
U1: nRF52840; NORDIC_NRF_4_AQFN50P700X700X85_HS-74N
X1: 32MHZ; NORDIC_NRF_BT-XTAL_2016_N
X2: 32.768kHz; NORDIC_NRF_1_XTAL_3215_N

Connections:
3V3: C6.1, C7.1, C8.1, C12.1, C14.1, C19.1, C25.1, C33.1, IC3.3 (VDDIO), IC3.7 (VDD), IC3.10 (CSB), IC9.E2 (VOUT_1), IC9.E3 (VOUT_2), J2.1, R17.2, R18.2, TP_3.3V.TP, TP_3V3.TP, U1.P$A22 (VDD), U1.P$AD14 (VDD), U1.P$AD23 (VDD), U1.P$B1 (VDD), U1.P$W1 (VDD), U1.P$Y2 (VDDH); also elsewhere on the board
ALERT: U1.P$J24 (P0.10/NFC2); also elsewhere on the board
D+: U1.P$AD6 (D+); also elsewhere on the board
D-: U1.P$AD4 (D-); also elsewhere on the board
DEC1: C5.1, U1.P$C1 (DEC1)
DEC3: C11.1, U1.P$D23 (DEC3)
DEC4_6: C10.1, C15.1, C16.1, L3.2, U1.P$B5 (DEC4), U1.P$E24 (DEC6)
EPD_BUSY: U1.P$AD12 (P0.17); also elsewhere on the board
EPD_CS: U1.P$K2 (P0.05/AIN3); also elsewhere on the board
EPD_DC: U1.P$AD10 (P0.15); also elsewhere on the board
EPD_RST: U1.P$AC11 (P0.16); also elsewhere on the board
GND: C1.2, C2.2, C3.2, C4.2, C5.2, C6.2, C7.2, C8.2, C9.2, C10.2, C11.2, C12.2, C13.2, C14.2, C15.2, C16.2, C17.1, C18.1, C19.2, C20.2, C21.2, C22.2, C23.1, C24.1, C25.2, C33.2, C37.1, C38.1, C39.2, IC1.D2 (GND), IC3.8 (GNDIO), IC3.9 (GND), IC9.B1 (VSEL), IC9.C1 (AGND), IC9.C2 (PGND_1), IC9.C3 (PGND_2), J2.3, J2.5, R3.1, R9.1, TP_GND.TP, U1.P$74 (VSS_PAD), U1.P$75 (VSS_PAD), U1.P$76 (VSS_PAD), U1.P$77 (VSS_PAD), U1.P$78 (VSS_PAD), U1.P$79 (VSS_PAD), U1.P$80 (VSS_PAD), U1.P$81 (VSS_PAD), U1.P$82 (VSS_PAD), U1.P$83 (VSS_PAD), U1.P$84 (VSS_PAD), U1.P$85 (VSS_PAD), U1.P$86 (VSS_PAD), U1.P$87 (VSS_PAD), U1.P$88 (VSS_PAD), U1.P$89 (VSS_PAD), U1.P$90 (VSS_PAD), U1.P$B7 (VSS), U1.P$F23 (VSS_PA), X1.2, X1.4; also elsewhere on the board
HAPTIC_EN: U1.P$U1 (P0.12); also elsewhere on the board
IMU_INT1: IC3.5 (INT1), U1.P$N1 (P0.08)
IMU_INT2: IC3.6 (INT2), U1.P$P2 (P1.08)
LX1: IC9.B2 (SW1_1), IC9.B3 (SW1_2), L7.1
LX2: IC9.D2 (SW2_1), IC9.D3 (SW2_2), L7.2
MOSI: U1.P$B13 (P0.03/AIN1); also elsewhere on the board
unnamed: C20.1, U1.P$AC5 (DEC3V3)
unnamed: C9.1, U1.P$N24 (DEC5)
unnamed: C3.1, L1.1, U1.P$H23 (ANT)
unnamed: C1.1, U1.P$B24 (XC1), X1.1
unnamed: C2.1, U1.P$A23 (XC2), X1.3
unnamed: L2.1, U1.P$B3 (DCC)
unnamed: L2.2, L3.1
unnamed: C13.1, U1.P$A18 (DEC2)
unnamed: IC1.D1 (TS/MR), R9.2
unnamed: IC9.D1 (SCL), R4.2
unnamed: IC9.E1 (SDA), R2.2
unnamed: IC3.1 (SDO), R3.2
P0.01/XL1: C17.2, U1.P$D2 (P0.00/XL1), X2.1
P0.01/XL2: C18.2, U1.P$F2 (P0.01/XL2), X2.2
P0.04: U1.P$J1 (P0.04/AIN2)
P0.09: U1.P$L24 (P0.09/NFC1)
P0.13: U1.P$AD8 (P0.13); also elsewhere on the board
P0.14: U1.P$AC9 (P0.14); also elsewhere on the board
P0.19: U1.P$AC15 (P0.19)
P0.20: U1.P$AD16 (P0.20)
P0.21: U1.P$AC17 (P0.21)
P0.22: U1.P$AD18 (P0.22)
P0.23: U1.P$AC19 (P0.23)
P0.24: U1.P$AD20 (P0.24)
P0.25: U1.P$AC21 (P0.25)
P0.26: U1.P$G1 (P0.26)
P0.27: U1.P$H2 (P0.27)
P0.28: U1.P$B11 (P0.28/AIN4)
P0.29: U1.P$A10 (P0.29/AIN5)
P0.30: U1.P$B9 (P0.30/AIN6)
P0.31: U1.P$A8 (P0.31/AIN7)
P1.01: U1.P$Y23 (P1.01); also elsewhere on the board
P1.02: U1.P$W24 (P1.02); also elsewhere on the board
P1.03: U1.P$V23 (P1.03)
P1.04: U1.P$U24 (P1.04)
P1.05: U1.P$T23 (P1.05)
P1.06: U1.P$R24 (P1.06)
P1.07: U1.P$P23 (P1.07)
P1.09: U1.P$R1 (P1.09)
P1.10: U1.P$A20 (P1.10)
P1.11: U1.P$B19 (P1.11)
P1.12: U1.P$B17 (P1.12)
P1.13: U1.P$A16 (P1.13)
P1.14: U1.P$B15 (P1.14)
P1.15: U1.P$A14 (P1.15)
PMIC_INT: IC1.A1 (!INT), U1.P$T2 (P0.11)
RESET: J2.6, TP_RESET.TP, U1.P$AC13 (P0.18/RESET)
RF: ANT1.1 (FEED), C4.1, C22.1, L1.2
SCK: U1.P$A12 (P0.02/AIN0); also elsewhere on the board
SCL: IC1.B1 (SCL), IC3.12 (SCX), R4.1, R17.1, TP_SCL.TP, U1.P$M2 (P0.07); also elsewhere on the board
SDA: IC1.C1 (SDA), IC3.2 (SDX), R2.1, R18.1, TP_SDA.TP, U1.P$L1 (P0.06); also elsewhere on the board
SWDCLK: J2.4, TP_SWDCLK.TP, U1.P$AA24 (SWDCLK)
SWDIO: J2.2, TP_SWDIO.TP, U1.P$AC24 (SWDIO)
SWO: TP_SWO.TP, U1.P$AD22 (P1.00)
VBAT: C37.2, IC1.C2 (BAT); also elsewhere on the board
VBUS: C21.1, C38.2, IC1.A2 (IN), U1.P$AD2 (VBUS); also elsewhere on the board
VREG: C23.2, C24.2, C39.1, IC1.B2 (SYS), IC9.A1 (EN), IC9.A2 (VIN_1), IC9.A3 (VIN_2), TP_VREG.TP

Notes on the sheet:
LiPo Charger
DC/DC
IMU
SWD

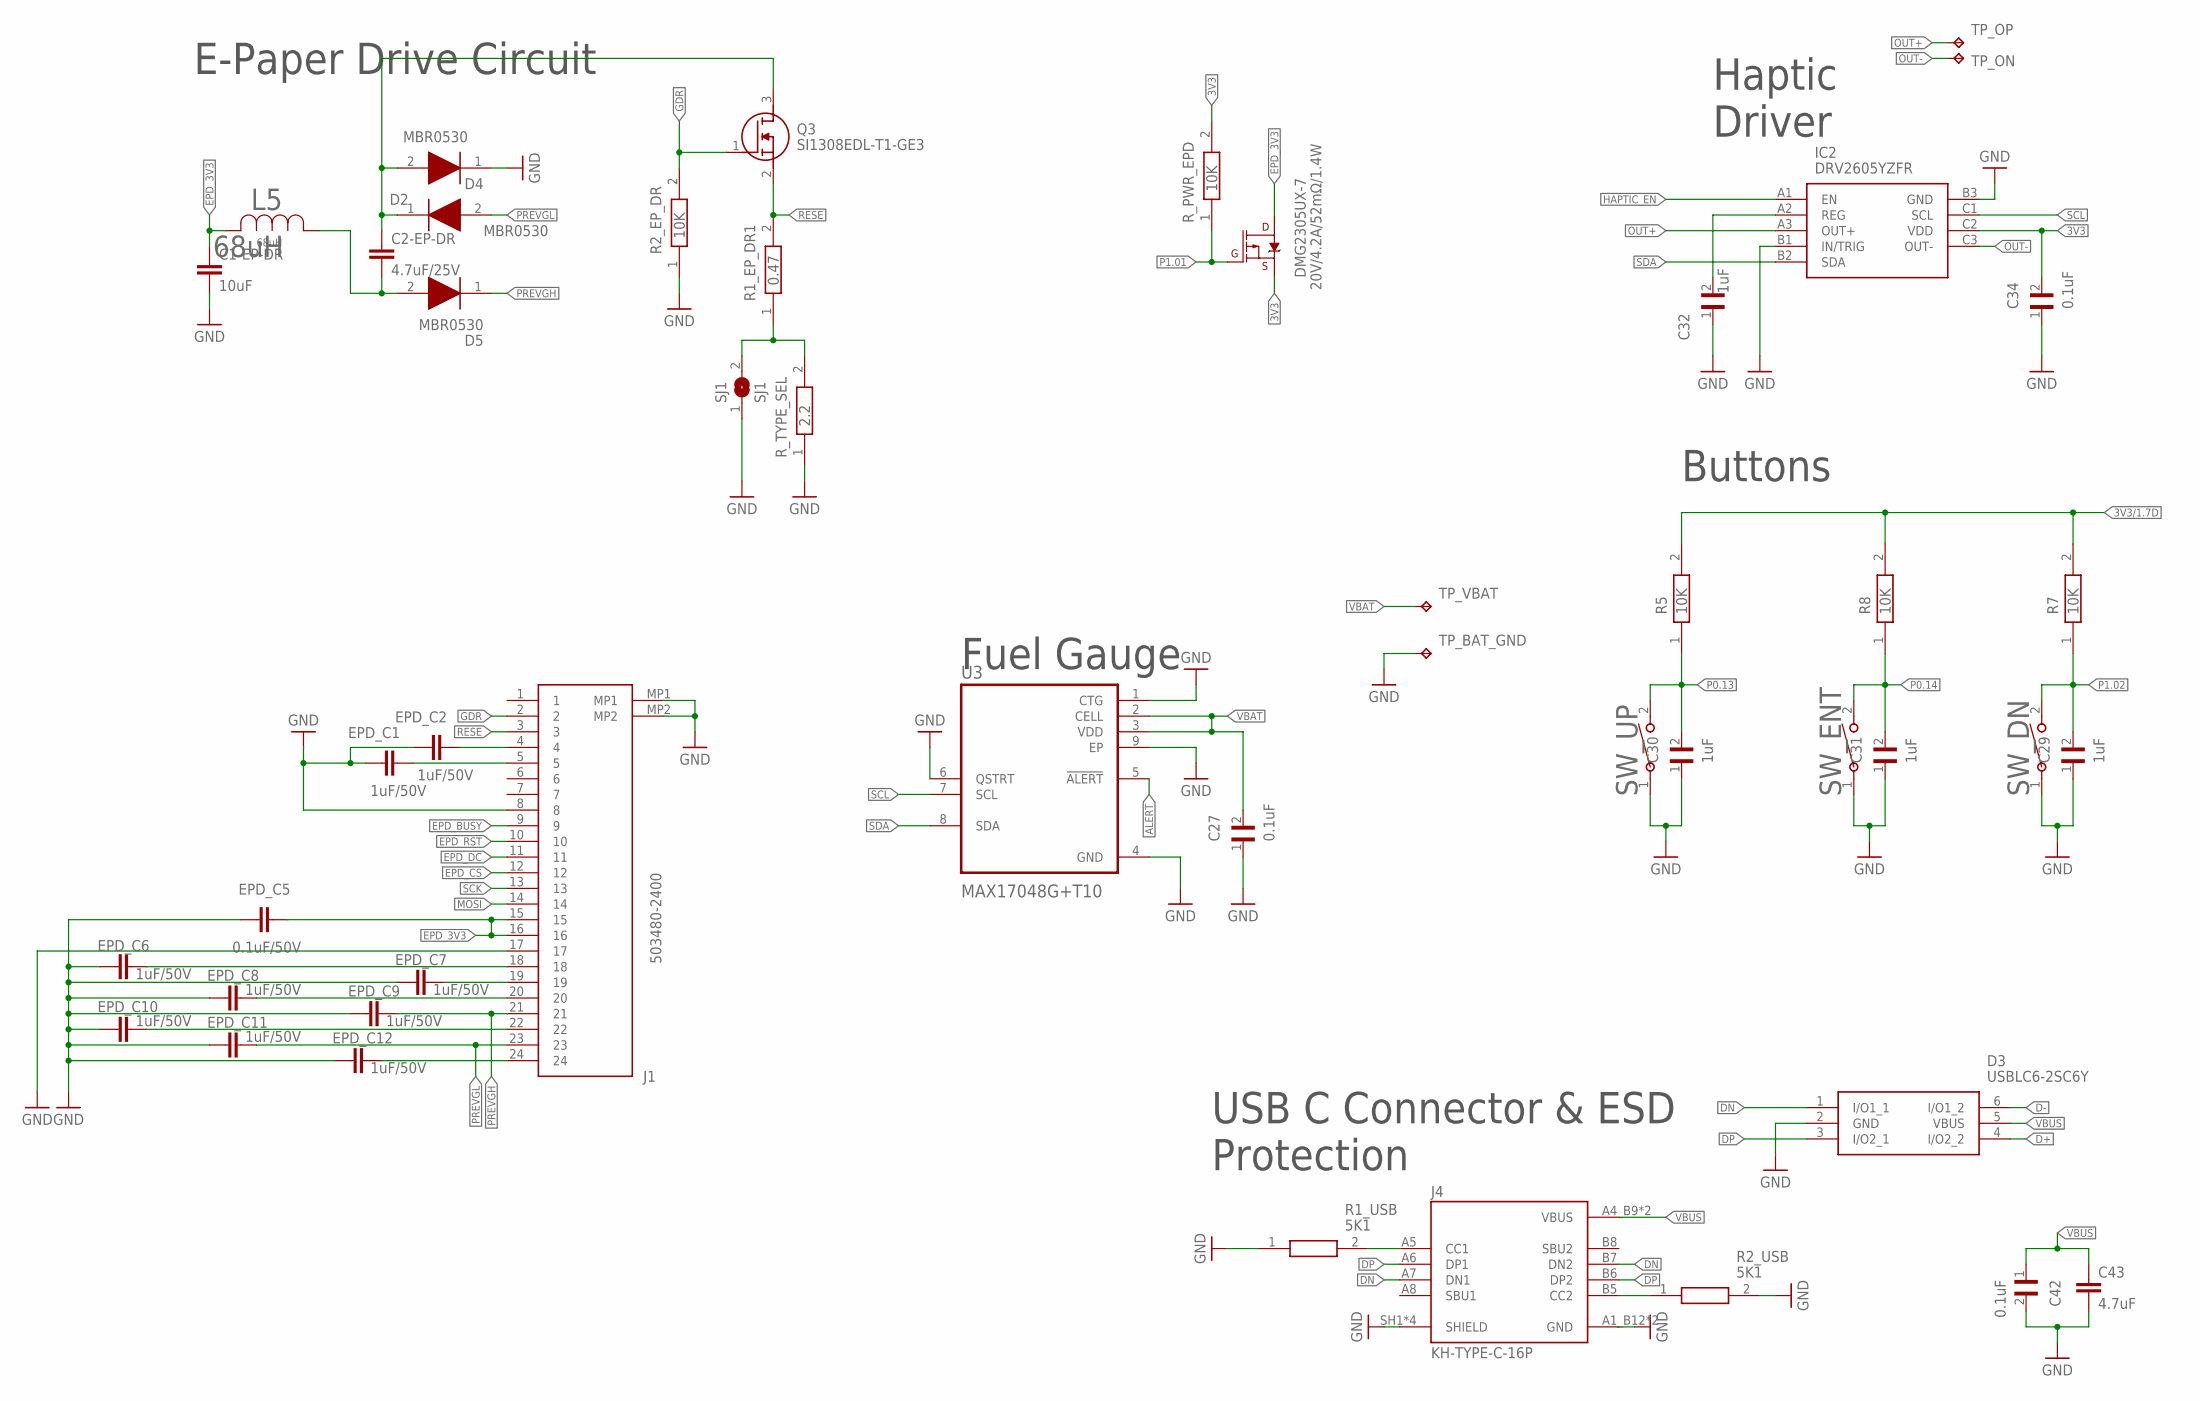
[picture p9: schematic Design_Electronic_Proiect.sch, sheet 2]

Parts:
C1-EP-DR: 10uF; NORDIC_NRF_3_RESC0402_L
C2-EP-DR: 4.7uF/25V; NORDIC_NRF_3_RESC0402_L
C27, C34, C42: 0.1uF; GRM011R60J152KE01L_2_CAPC0201X13N
C29, C30, C31, C32: 1uF; GRM011R60J152KE01L_2_CAPC0201X13N
C43: 4.7uF; NORDIC_NRF_3_RESC0402_L
D2, D4, D5: MBR0530; ESP32_C6_LIBRARY_5_SOD3716X135N
D3: USBLC6-2SC6Y; ESP32_C6_LIBRARY_3_SOT95P280X145-6N
DMG2305UX-7: 20V/4.2A/52mΩ/1.4W; ESP32_C6_LIBRARY_4_ESP32_C6_LIBRARY_4_ESP32_C6_LIBRARY_4_ES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
EPD_C1, EPD_C2, EPD_C6, EPD_C7, EPD_C8, EPD_C9, EPD_C10, EPD_C11, EPD_C12: 1uF/50V; NORDIC_NRF_3_RESC0402_L
EPD_C5: 0.1uF/50V; NORDIC_NRF_3_RESC0402_L
IC2: DRV2605YZFR; DRV2605YZFR_BGA9C50P3X3_144X144X62
J1: 503480-2400; 503480-2400_5034802400
J4: KH-TYPE-C-16P; KH-TYPE-C-16P_KINGHELM_KH-TYPE-C-16P
L5: 68uH; ESP32_C6_LIBRARY_2_IND_4828-WE-TPC_WRE
Q3: SI1308EDL-T1-GE3; ESP32_C6_LIBRARY_6_SOT65P210X110-3N
R1_EP_DR1: 0.47; CPF0201D7K68C1_0201
R1_USB, R2_USB: 5K1; CPF0201D7K68C1_0201
R2_EP_DR, R5, R7, R8: 10K; CPF0201D7K68C1_0201
R_PWR_EPD: 10K; CPF0201D7K68C1_0201
R_TYPE_SEL: 2.2; CPF0201D7K68C1_0201
SJ1: SJ1; ESP32_C6_LIBRARY_7_JUMPER_SJ
SW_DN: 2025-10-22_07-23-44_LIBRARY_EVP-AKE31ASW_EVP-AKE3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; 2025-10-22_07-23-44_LIBRARY_SW_EVP-AKE31A_PAN
SW_ENT: 2025-10-22_07-23-44_LIBRARY_EVP-AKE31ASW_EVP-AKE3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; 2025-10-22_07-23-44_LIBRARY_SW_EVP-AKE31A_PAN
SW_UP: 2025-10-22_07-23-44_LIBRARY_EVP-AKE31ASW_EVP-AKE3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; 2025-10-22_07-23-44_LIBRARY_SW_EVP-AKE31A_PAN
TP_BAT_GND: HECTOR_WATCH_1_TPTP20R; HECTOR_WATCH_1_TP20R
TP_ON: HECTOR_WATCH_1_TPTP20R; HECTOR_WATCH_1_TP20R
TP_OP: HECTOR_WATCH_1_TPTP20R; HECTOR_WATCH_1_TP20R
TP_VBAT: HECTOR_WATCH_1_TPTP20R; HECTOR_WATCH_1_TP20R
U3: MAX17048G+T10; ESP32_C6_LIBRARY_SON50P200X200X80-9N

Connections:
3V3: C34.2, DMG2305UX-7.2 (S), IC2.C2 (VDD), R_PWR_EPD.2; also elsewhere on the board
3V3/1.7D: R5.2, R7.2, R8.2
ALERT: U3.5 (!ALERT); also elsewhere on the board
D+: D3.4 (I/O2_2); also elsewhere on the board
D-: D3.6 (I/O1_2); also elsewhere on the board
DN: D3.1 (I/O1_1), J4.A7 (DN1), J4.B7 (DN2)
DP: D3.3 (I/O2_1), J4.A6 (DP1), J4.B6 (DP2)
EPD_3V3: C1-EP-DR.1, DMG2305UX-7.3 (D), EPD_C5.2, J1.15, J1.16, L5.2
EPD_BUSY: J1.9; also elsewhere on the board
EPD_CS: J1.12; also elsewhere on the board
EPD_DC: J1.11; also elsewhere on the board
EPD_RST: J1.10; also elsewhere on the board
GDR: J1.2, Q3.1 (G), R2_EP_DR.2
GND: C1-EP-DR.2, C27.1, C29.1, C30.1, C31.1, C32.1, C34.1, C42.2, C43.2, D3.2 (GND), D4.1 (K), EPD_C1.1, EPD_C2.1, EPD_C5.1, EPD_C6.1, EPD_C7.1, EPD_C8.1, EPD_C9.1, EPD_C10.1, EPD_C11.1, EPD_C12.1, IC2.B1 (IN/TRIG), IC2.B3 (GND), J1.8, J1.17, J1.MP1, J1.MP2, J4.A1_B12 (GND), J4.A12_B1 (GND), J4.SH1 (SHIELD), J4.SH2 (SHIELD), J4.SH3 (SHIELD), J4.SH4 (SHIELD), R1_USB.1, R2_EP_DR.1, R2_USB.2, R_TYPE_SEL.1, SJ1.1, SW_DN.1, SW_ENT.1, SW_UP.1, TP_BAT_GND.TP, U3.1 (CTG), U3.4 (GND), U3.6 (QSTRT), U3.9 (EP); also elsewhere on the board
HAPTIC_EN: IC2.A1 (EN); also elsewhere on the board
MOSI: J1.14; also elsewhere on the board
unnamed: C2-EP-DR.2, D5.2 (A), L5.1
unnamed: C2-EP-DR.1, D2.1 (K), D4.2 (A), Q3.3 (D)
unnamed: R1_EP_DR1.1, R_TYPE_SEL.2, SJ1.2
unnamed: C32.2, IC2.A2 (REG)
unnamed: J4.A5 (CC1), R1_USB.2
unnamed: EPD_C2.2, J1.4
unnamed: J4.B5 (CC2), R2_USB.1
unnamed: EPD_C1.2, J1.5
unnamed: EPD_C6.2, J1.18
unnamed: EPD_C7.2, J1.19
unnamed: EPD_C8.2, J1.20
unnamed: EPD_C10.2, J1.22
unnamed: EPD_C12.2, J1.24
OUT+: IC2.A3 (OUT+), TP_OP.TP
OUT-: IC2.C3 (OUT-), TP_ON.TP
P0.13: C30.2, R5.1, SW_UP.2; also elsewhere on the board
P0.14: C31.2, R8.1, SW_ENT.2; also elsewhere on the board
P1.01: DMG2305UX-7.1 (G), R_PWR_EPD.1; also elsewhere on the board
P1.02: C29.2, R7.1, SW_DN.2; also elsewhere on the board
PREVGH: D5.1 (K), EPD_C9.2, J1.21
PREVGL: D2.2 (A), EPD_C11.2, J1.23
RESE: J1.3, Q3.2 (S), R1_EP_DR1.2
SCK: J1.13; also elsewhere on the board
SCL: IC2.C1 (SCL), U3.7 (SCL); also elsewhere on the board
SDA: IC2.B2 (SDA), U3.8 (SDA); also elsewhere on the board
VBAT: C27.2, TP_VBAT.TP, U3.2 (CELL), U3.3 (VDD); also elsewhere on the board
VBUS: C42.1, C43.1, D3.5 (VBUS), J4.A4_B9 (VBUS), J4.A9_B4 (VBUS); also elsewhere on the board

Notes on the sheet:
E-Paper Drive Circuit
Haptic Driver
Buttons
Fuel Gauge
USB C Connector & ESD Protection

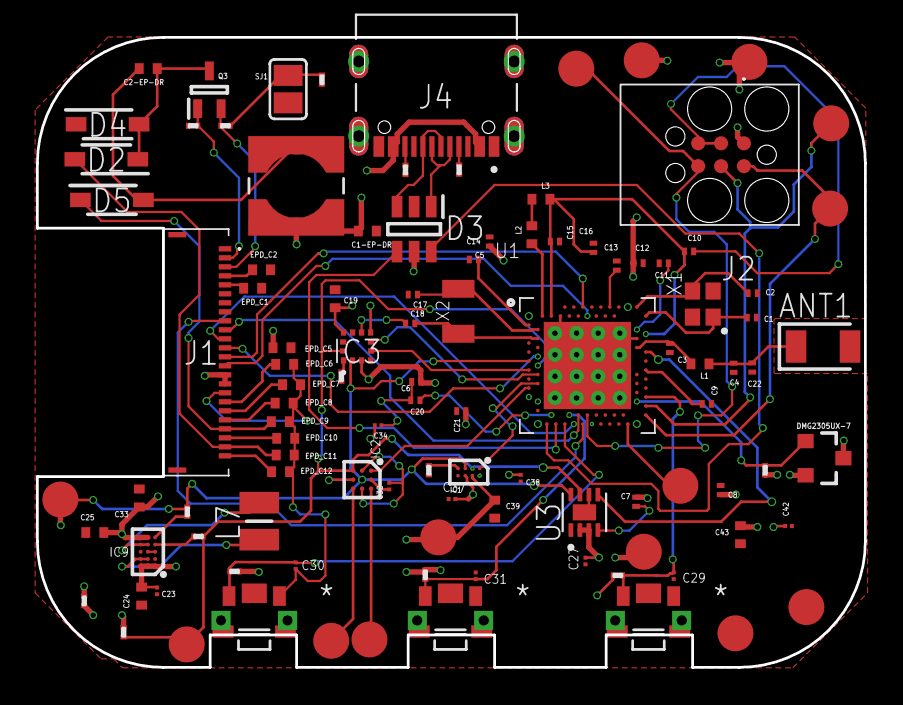
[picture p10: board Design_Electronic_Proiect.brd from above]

Board: 2 copper layers, 46.0 x 35.0 mm, 105 parts (0 on the bottom side), 71 nets.

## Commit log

2026-03-29 Created Hardware directory containing electrical scheme and 2D PCB
    [Design_Electronic_Proiect.brd, Design_Electronic_Proiect.sch]
2026-03-29 Worken on some mistakes on PCB. Created BOM and Pick and Place.
    [Design_Electronic_Proiect.brd, bom.csv.csv, pick_and_place.csv.csv]
2026-03-29 Solved BOM and pick and place name issue.
    [bom.csv, pick_and_place.csv]

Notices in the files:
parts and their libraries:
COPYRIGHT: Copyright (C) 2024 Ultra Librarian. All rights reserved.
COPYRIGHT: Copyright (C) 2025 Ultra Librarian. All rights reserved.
